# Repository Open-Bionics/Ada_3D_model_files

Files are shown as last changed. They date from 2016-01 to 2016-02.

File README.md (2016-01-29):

# Ada_3D_model_files

This folder contains the design files for the Ada hand. 
The Ada hand is named after Ada Lovelace, "the first computer programmer". 
This hand is not a prosthesis, it is intended as a development kit. 
Components such as the circuit board and motors are available for purchase soon from www.openbionics.com

This work is licensed under the Creative Commons Attribution-ShareAlike 4.0 International License.
To view a copy of this license, visit http://creativecommons.org/licenses/by-sa/4.0/
org.

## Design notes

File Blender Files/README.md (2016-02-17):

This repositorty contains all the CAD models for Open Bionics products. 
The files are created in Blender, a free to use program available from www.blender.org

Several of the "Boolean" models that are easier to design parametrically are created in Autodesk Fusion 360. These included in the Blender files, having been exported from Fusion 360 as an STL. Fusion 360 is available from http://www.autodesk.co.uk/products/fusion-360/overview

This work is licensed under the Creative Commons Attribution-ShareAlike 4.0 International License.
To view a copy of this license, visit http://creativecommons.org/licenses/by-sa/4.0/

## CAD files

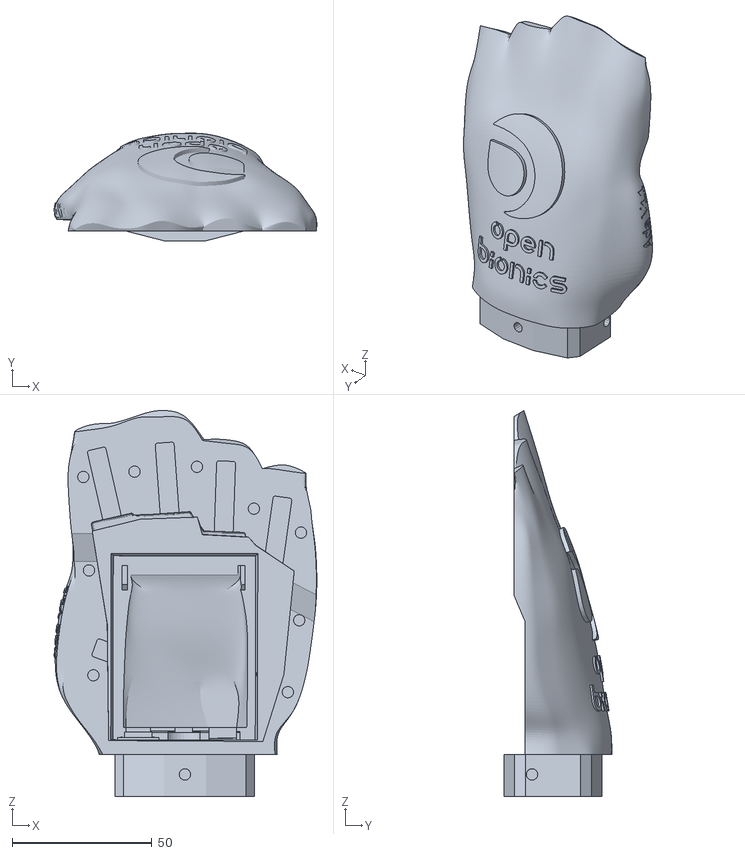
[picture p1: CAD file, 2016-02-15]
STLs/Left Hand/L_Ada_v1.1_Back_Cover.stl
94.1 x 38.6 x 138.3

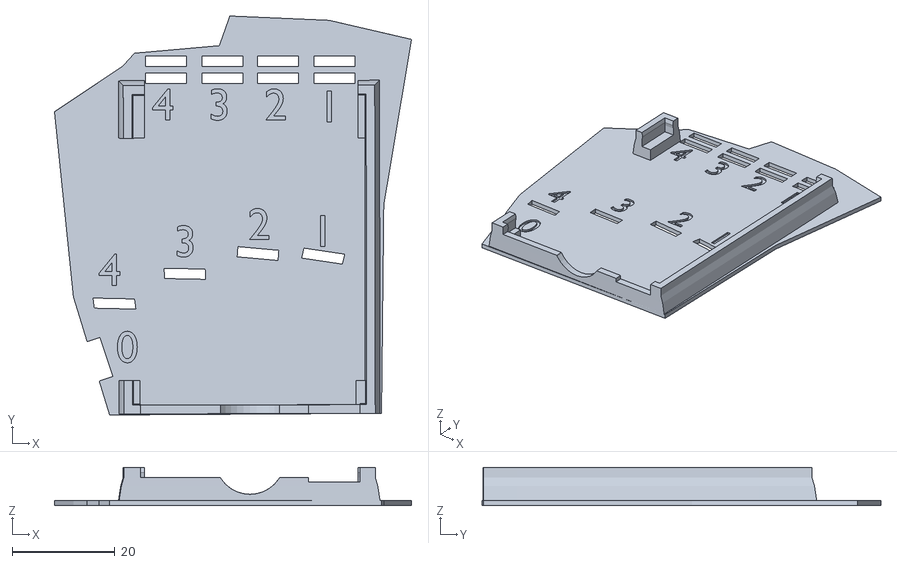
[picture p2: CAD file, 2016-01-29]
STLs/Left Hand/L_Ada_v1.1_PCB_Tray_Upper.stl
69.6 x 77.8 x 7.50

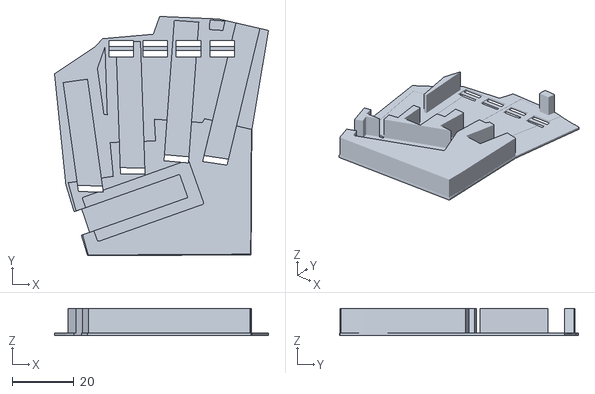
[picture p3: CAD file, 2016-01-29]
STLs/Right Hand/R_Ada_v1.1_PCB_Tray_Lower.stl
69.6 x 77.8 x 8.82

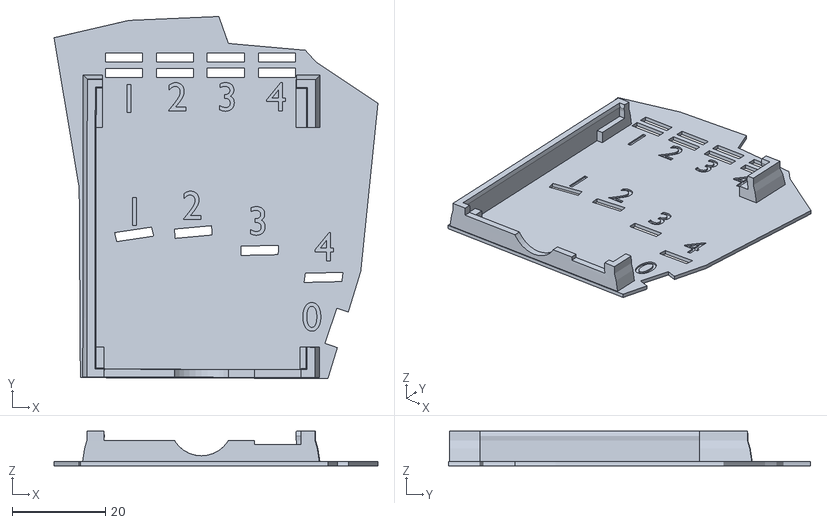
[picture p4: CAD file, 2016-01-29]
STLs/Right Hand/R_Ada_v1.1_PCB_Tray_Upper.stl
69.6 x 77.8 x 7.41

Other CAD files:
STLs/Right Hand/R_Ada_v1.1_Back_Cover.stl
STLs/Left Hand/L_Ada_v1.1_PCB_Tray_Lower.stl

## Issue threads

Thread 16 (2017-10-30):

STEP FILE

amunizp, 2017-10-30:
https://github.com/Open-Bionics/Ada_3D_model_files
README mentions that files were done using Fusion 360. Could you provide the STEP file? the blender files thumb seems to have the hole off centre.

Having a STEP file is a more standard way of sharing engineering CAD files. STL is just a cloud of points not easily modified.

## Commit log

2016-01-07 Widened tendon channels
2016-01-07 Revert "Widened tendon channels"
    This reverts commit ba99583c17821896a7720b9037648f5cc164873b.
2016-01-11 2016 Week 1 updates
    v003 - Removed distal joints from fingers. Tidied mesh on fingers and
    thumb. - J Raines.
    v004 - Tidied mesh around proximal thumb phalanx. - J Raines.
    v005 - Tidied mesh on palm near thumb. Flattened joint internal faces
    and increased joint angles (phi). Made small adjustments (of less than
    2°) to the finger joint angles in the z axis; this aligned them more
    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
2016-01-11 v014
    v014 - Improved PCB tray so that all the PQ12 cables are inline before
    going into the PCB. I also numbered the slots with embossed lettering to
    aid assembly.
2016-01-12 v015
    v015 - Further improved booleans for dorsal cover. The cover now closes
    tightly (0.4 mm) around the PCB and PCB tray. The proximal end of the
    cable tray boolean was slightly extruded to prevent the cover coliding
    with the protruding connectors on the proximal end of the board. The
    logo was re-done; it now is a 2D low-poly model with a stack of three
    modifiers. Subsurf, Shrinkwrap (to dorsal cover), and Solidify (1.5 mm,
    0.0 offset). This is a more flexible arrangement.
2016-01-12 v016
    v016 - Updated PCB model from CES board to Almond v1.2. The motor
    connectors were slightly taller than previously modelled so I adjusted
    the PCB bracket to match. The base layer was thinned by 1 mm and the
    labelling numbers are now recessed rather than embossed. The lower tray
    was adjusted to grip the motors tighter, there is now no tolerance.
2016-01-13 v017
    I created a new PCB boolean to reflect the new board and so the Dorsal
    Cover fits tightly around the connectors. Added Cable Port boolean to
    PCB tray so that it doesn't prevent a user from fully inserting the
    connectors. Slightly lowered the proximal plane of the Master - Dorsal
    block. This puts it more inline with the thumb joint and allows the
    thumb back stop to be bigger without self-intersecting.
2016-01-13 v018
    v018 - Standardised proximal finger joints. Each joint is made of two 6
    mm wide, 1.5 mm thick, and 1 mm long struts. The interface is fully
    squared. For distal joints, they struts are 5 mm W x 1.2 mm T x 0.8 mm
    L.
2016-01-26 Restructuring of files
    Repository is now Ada hand specific. Ada folder removed. STL and Blender
    files will both be listed so created a Blender file folder.
2016-01-26 To v031
    v019 - Exagerate thumb backstop after joint adjustment. Adjusted PQ12
    boolean so thumb actuator can be inserted with its horn extended.
    |--v019b - Bent fingers back by an extra 10° to 40° relative to the palm
    (25° relative to the build plate). This puts the fingertips aproximately
    level with the wrist, reducing the amount of support under the fingers.
    |--v019bb - Thickened the PCB bracket back to a mid section thickness of
    3 mm. This thickness printed well during earlier trials. Thinner ones
    tend to be too floppy and have small in the surface. Tidied the PCB and
    PCB bracket booleans for the dorsal cover.
    v020 - Merged v019bb, removed v019b changes as printing the fingers at a
    stee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
2016-01-26 Added Right hand files
    [R_Ada_Back_Cover.stl, R_Ada_PCB_Tray_Lower.stl, R_Ada_PCB_Tray_Upper.stl]
2016-01-27 Fix tendon channel
    Tendon channel boolean was not working on 4th finger. 4th finger face
    normals were pointing inwards. Flipping them fixed it.
2016-01-27 Add left hand STLS
    [L_Ada_Back_Cover.stl, L_Ada_PCB_Tray_Lower.stl, L_Ada_PCB_Tray_Upper.stl]
2016-01-27 Fixed PCB tray upper & lower
    [R_Ada_PCB_Tray_Lower.stl, R_Ada_PCB_Tray_Upper.stl]
2016-01-27 Updated PCB Upper part orientation
    [R_Ada_PCB_Tray_Upper.stl]
2016-01-28 Fix STL cable port glitch
    The PCB connector boolean was not applying correctly. Tabbing in and out
    of edit mode on the PCB boolean fixed this. I saved out the corrected
    STLs for the back cover for a left and right hand. NOTE this glitch
    still occurs every time the file is opened. Need to find root.
    [L_Ada_Back_Cover.stl, R_Ada_Back_Cover.stl]
2016-01-29 STL fix
    Resave all STLs via applying all booleans in a separate, throw away
    file. This avoids what appears to be a glitch in Blender where modifiers
    aren't applied correctly on opening a file. This will be investigated
    further. Doing this highlighted a few small errors in creases in the
    fingers which were corrected too.
    [L_Ada_Back_Cover.stl, L_Ada_PCB_Tray_Lower.stl, L_Ada_PCB_Tray_Upper.stl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]
2016-01-29 Lengthen joints
    All joints increase from 1 mm length to 1.5 mm to ensure the gaps
    between finger and palm come out in printing. The joints will need to be
    made thicker to compensate.
2016-01-29 Thicken joints
    Thickened all joints by 0.2 mm in the z axis in the direction of the
    palm. This should compensate for the increased lengths in the last
    commit.
2016-01-29 Further STL Fix
    The PCB boolean has itself a boolan union to a child. This was failing
    in a similar way to the previously fixed boolean differences in the
    Dorsal Cover.
    [L_Ada_Back_Cover.stl, R_Ada_Back_Cover.stl]
2016-01-29 Adjust stiffness by finger mass
    The 4th finger usually prints well so it was taken as a base. The other
    joints were stiffened proportionally to their fingers mass. For example,
    the 2nd finger is 1.6 x more massive and therefore the 2nd finger joint
    was made 1.6 x stiffer. This was done by widening the two branches of
    the joint in the fingers local Y axis, moving the inner faces inwards.
    This approach was taken as joint stiffness is less sensitive to changes
    in branch width (compared to height) and so changing width can be used
    as a "fine tuner".
2016-01-29 Export previous changes to STL for right hand
2016-02-02 Step removal
    A step of less than 1 mm just next to the finger joint was thought to be
    causing curling at the joint and floppiness. This commit flattens the
    step.
2016-02-05 Make joints supportable
    Changed the geometry of the proximal finger joints so that support can
    reach all the way into the joint. Also removed a legacy blend1 file.
2016-02-05 Add step to finger joints
    Going the other way from two commits ago
    (5bbb657ae76937c2f8f105d5afaf97db4f739e10). Instead of removing the step
    to avoid the problem seen at the sides of the hand, the step is made
    sufficiently large to act as a buffer against curling.
2016-02-08 Re-apply PCB boolean to clear glitch
    [L_Ada_Back_Cover.stl]
2016-02-08 Add PCB tray Boolean to hand
    The PCB tray clashed with the palm after the level of the interior was
    moved away from the palm. This Boolean allows the tray to tuck into the
    palm.
2016-02-08 Thicken back cover to account for moved M3 bolts
    [R_Ada_Back_Cover.stl]
2016-02-11 Create dip for PCB tray
2016-02-12 Edit thumb to print better.
    Removed as many overhanging sharp corners as possible. Adjusted
    proximal's shape so that it has a flatter bottom and more vertical sides
    to remove longer overhangs.
2016-02-12 Update right STL
2016-02-12 Adjust back cover
    Squared corners of backstops to increase contact area with fingers.
    Moved them all outward as well to make fingers more flexed at rest.
    Incremented version number to 1.1 on dorsal cover. Increased thickness
    of cover text. Also updated STL
2016-02-12 Update back cover STL
    [R_Ada_Back_Cover.stl]
2016-02-15 Update Left with changes to right
    Right hand model saved over left and reflected all required components
    about X axis. This ensures all changes are moved across. STLs updated
    for Palm and Back Cover. Old Blend1 file removed
    [L_Ada_Back_Cover.stl]
2016-02-15 Orientate STLs
    Re-orientated new STLs for printing
    [L_Ada_Back_Cover.stl, R_Ada_Back_Cover.stl]
2016-02-15 Update version numbers to v1.1
    Also added version numbers to STLs
    [L_Ada_v1.1_Back_Cover.stl, L_Ada_v1.1_PCB_Tray_Lower.stl, L_Ada_v1.1_PCB_Tray_Upper.stl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]
2016-02-16 Manual merge of FingerJointDorsalSlots
    Replaced fingers on bot Left and Right hands with those of the
    FingerJointDorsalSlots. This angles the dorsal slots of the distal
    finger joints vertically relative to the print bed to improve print
    quality.
2016-02-16 Revert "Manual merge of FingerJointDorsalSlots"
    This reverts commit 266d2c8d5ce1fb7e83710f55e746c882d39b5585.
2016-02-16 Make distal joint dorsal slots vertical relative to print bed
2016-02-22 Mirror Right Palm
    Left hand palm STL has a missing Boolean. Due to a glitch in Blender.
    Yet to be fixed. Mirrored right hand as temporary fix.
2016-02-23 Fix Boolean
    Fixed the PCB tray Boolean by reordering the Booleans so that the PCB
    tray Boolean applied before the PQ12 Boolean
